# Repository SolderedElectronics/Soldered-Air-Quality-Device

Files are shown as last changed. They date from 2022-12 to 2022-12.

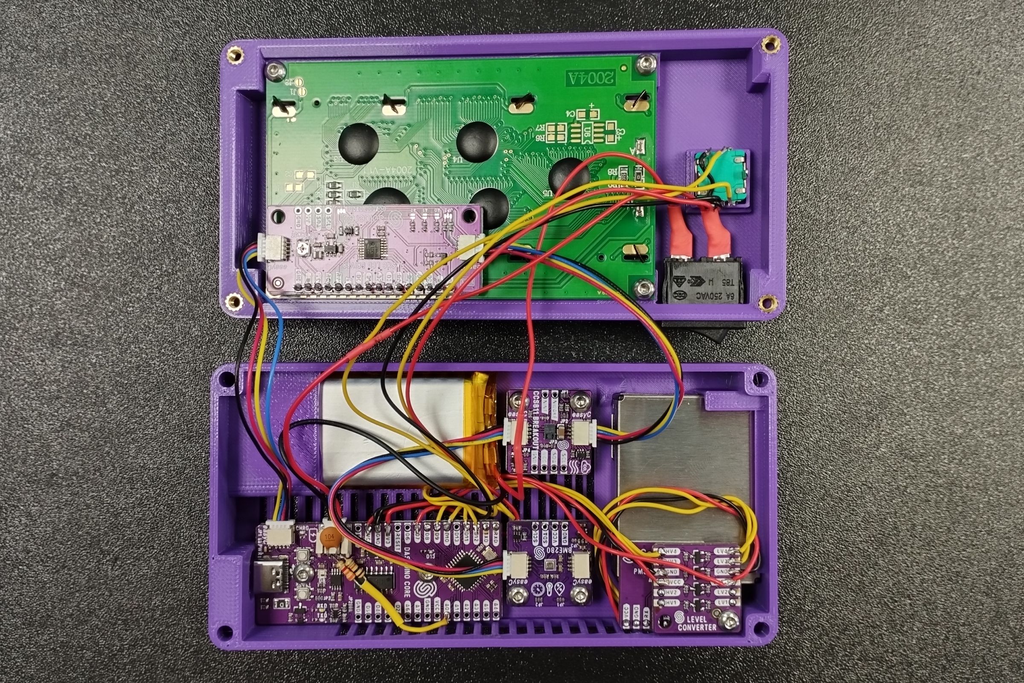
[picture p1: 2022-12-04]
Images/DeviceInside.jpg

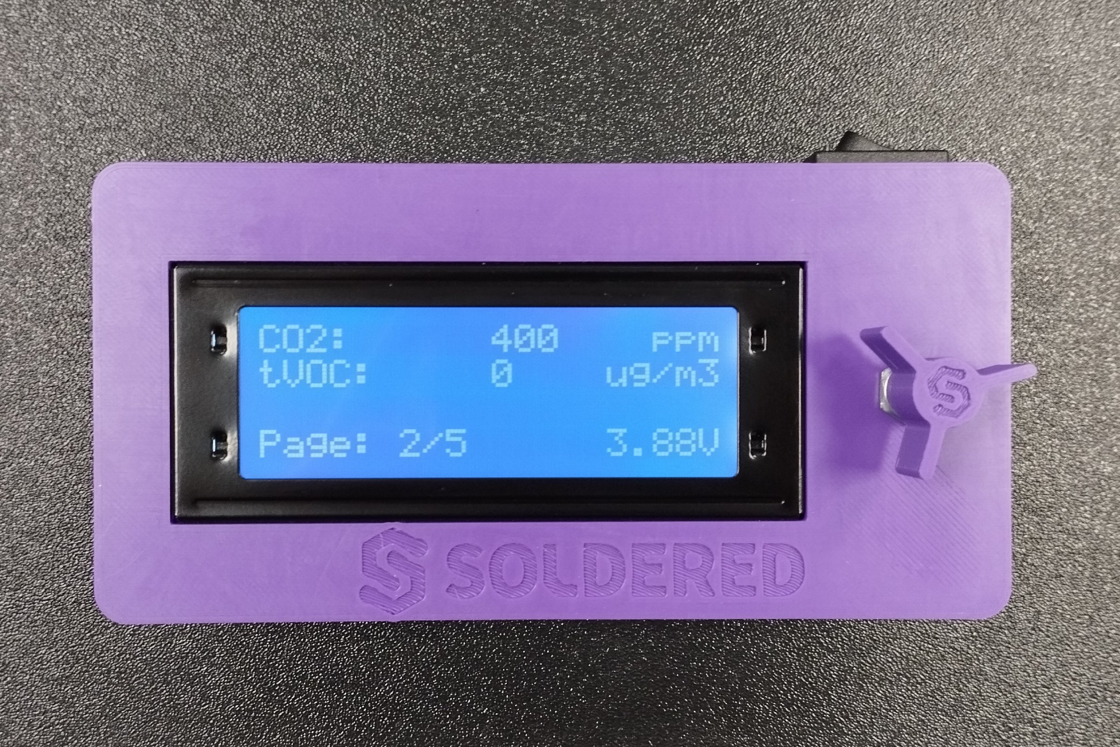
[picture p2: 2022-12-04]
Images/Page2.jpg

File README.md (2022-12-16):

# Device for measuring air quality parameters

In order to have an insight into the air quality in the places where we live, we designed a simple device that measures the parameters that determine air quality, namely: temperature, humidity, pressure, CO2, and the concentration of small-sized particles that are dispersed throughout the air. To measure these parameters, we chose sensors: BME680, CCS811, and PMS7003. In order to display the data to the user, there is an LCD screen that can display 80 characters, 20 in each of the 4 lines. The sensors are controlled by the Dasduino Core, and to make the device portable, it can also run on a battery. Navigation through a simple interface is made possible by a rotary encoder, and the 3D-printed case places all the sensors in a small space and gives it that unique maker character.

Air quality device

# Wiring diagram
Sensors and other components are connected according to the wiring diagram shown below.

schematic

## Used electronic components

* Dasduino CORE - [link](https://soldered.com/product/dasduino-core-2/)
* Enviromental & air quality sensor BME680 breakout - [link](https://soldered.com/product/senzor-kvalitete-zraka-i-okoline-bme680-2/)
* Air quality sensor CCS811 breakout - [link](https://soldered.com/product/senzor-kvalitete-zraka-ccs811-2/)
* PMS7003 senzor PM10, PM2.5 - [link](https://soldered.com/hr/proizvod/pms7003-senzor-pm10-pm2-5/) + PMS7003 sensor adapter - [link](https://soldered.com/product/adapter-za-pms7003-senzor-2/)
* Logic level converter board - [link](https://soldered.com/product/pretvarac-logickih-razina-2/)
* LCD display16x4 white/blue - [link](https://soldered.com/product/lcd-ekran-16x4-bijelo-plavi-2/) + I2C LCD driver board - [link](https://soldered.com/hr/proizvod/i2c-lcd-driver-board/)
* Rotary encoder 20mm with pushbutton - [link](https://soldered.com/product/rotary-encoder-20mm-s-pushbuttonom-2/)
* Li-ion battery 1800mAh 3.7V - [link](https://soldered.com/product/li-ion-baterija-1800mah-3-7v-2/)
* SPST panel switch elongated - [link](https://soldered.com/product/spst-panel-prekidac-duguljasti-2/)
* Resistor R1 = 10K (it's situated in [Resistor kit 400](https://soldered.com/product/set-otpornika-400-2/))
* Resistor R2 = 3.3K (it's situated in [Resistor kit 400](https://soldered.com/product/set-otpornika-400-2/))
* Ceramic capacitor 100nF 50V - [link](https://soldered.com/product/keramicki-kondenzator-100nf-50v-2/)

## Consumable material for assembling:
* PLA Soldered purple filament
* M3 Threaded inserts
* 9x Screw M3 5mm HEX - [link](https://soldered.com/product/vijak-m3-5mm-hex-2/)
* 4x Screw M3 12mm HEX - [link](https://soldered.com/product/vijak-m3-12mm-hex-2/)
* Prototyping wire AWG25 - [link](https://soldered.com/product/ica-za-prototipiranje-10m-crvena-awg25-2/)
* 3x easyC cable 10cm - [link](https://soldered.com/product/easyc-kablic-10cm-2/)
* Heatshrink - [link](https://soldered.com/product/set-termobuzira-2/)

# 3D case
In order for all the sensors and electronics to be in one place and at the same time look nice, a case was designed that was printed on a 3D printer. In order for the air to flow through the case for the sensors to measure correctly, there are openings on the back and on the top and bottom.

3d case

When we place all the sensors in the intended place in the case, it looks like this

Device inside with bme680

# How to use this device?
The device has a rotary encoder that controls the device. By turning the rotary encoder, we change the pages on which the readings are displayed. The device automatically refreshes the data every 5 seconds (it can be changed in the code by simply changing the constant), but if we want immediate reading and refreshing of the page, it is possible by pressing the button of the rotary encoder. BME680 and PMS7003 are relatively fast and with them a new reading will be obtained, while CCS811 is not so fast and if we refresh its measurements too quickly sometimes it will not be able to measure them and old measurements will be displayed. These times are of the order of several tenths, and this will not be noticed if the device refreshes itself. Depending on how many sensors are connected, we have a different number of pages, and the pages go in a circle, i.e. from the last page by turning forward, we switch to the first page and vice versa.

Page2
Page3
Page4

In the bottom right corner is the battery voltage. When the Dasduino is connected to 5V via the USB-c port, the voltage can vary because it is charging the battery. There is a switch on the device that turns the battery on and off from the circuit, i.e. when the device is connected to 5V, the battery will charge only if the switch is set to 1, otherwise, the battery will not charge.

Device From Above

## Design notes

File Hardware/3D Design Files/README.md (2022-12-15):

# 3D printing

Here are the files needed for 3D printing. We used the Prusa Mk3s+ 3D printer and the Prusa slicer for printing. 
The 3D printer settings are as follows: 
* Default speed for mk3 printers
* 15% infill
* 0.2 mm layer height 

We used PLA Soldered purple filament.

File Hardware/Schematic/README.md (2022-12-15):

schematic

The sensors and other components are connected according to the schematic. The BME680, CCS811, and the LCD support easyC so connected to the Dasduino through it for simplicity. The order of connection of easyC is not important and it does not have to be connected in the same order as in the wiring diagram. PMS7003 is connected to the PMS adapter and the same adapter to the Dasduino. It is important to note that we have to connect the serial communication through a logic level converter because the PMS uses 3.3V logic levels and the Dasduino uses 5V logic levels. The adapter independently raises the voltage to 5V, which powers the PMS sensor itself, so we don't have to take this in mind. To measure the battery voltage, it is necessary to make a voltage divider that will lower the battery voltage to the range from 0 to 1.1V so that it can be measured correctly using an internal reference, and for this, resistances R1 = 10K and R2 = 3.3K were used. If we were to measure the voltage using a 5V reference, as the battery would discharge, the reference voltage would be lower and lower and the battery reading would always be incorrect. By using an internal reference, we solved that problem because it is always fixed. To stabilize the voltage, a C1 = 100 uF capacitor was added in parallel to the battery. A switch has been added to the circuit so that it disconnects the + pole of the battery instead of going directly to the Dasduino, and it is important to note that the battery cannot be charged if the switch is off.

# Used electronic components

* Dasduino CORE - [link](https://soldered.com/product/dasduino-core-2/)
* Enviromental & air quality sensor BME680 breakout - [link](https://soldered.com/product/senzor-kvalitete-zraka-i-okoline-bme680-2/)
* Air quality sensor CCS811 breakout - [link](https://soldered.com/product/senzor-kvalitete-zraka-ccs811-2/)
* PMS7003 senzor PM10, PM2.5 - [link](https://soldered.com/hr/proizvod/pms7003-senzor-pm10-pm2-5/) + PMS7003 sensor adapter - [link](https://soldered.com/product/adapter-za-pms7003-senzor-2/)
* Logic level converter board - [link](https://soldered.com/product/pretvarac-logickih-razina-2/)
* LCD display16x4 white/blue - [link](https://soldered.com/product/lcd-ekran-16x4-bijelo-plavi-2/) + I2C LCD driver board - [link](https://soldered.com/hr/proizvod/i2c-lcd-driver-board/)
* Rotary encoder 20mm with pushbutton - [link](https://soldered.com/product/rotary-encoder-20mm-s-pushbuttonom-2/)
* Li-ion battery 1800mAh 3.7V - [link](https://soldered.com/product/li-ion-baterija-1800mah-3-7v-2/)
* SPST panel switch elongated - [link](https://soldered.com/product/spst-panel-prekidac-duguljasti-2/)
* Resistor 10K (it's situated in [Resistor kit 400](https://soldered.com/product/set-otpornika-400-2/))
* Resistor 3.3K (it's situated in [Resistor kit 400](https://soldered.com/product/set-otpornika-400-2/))
* Ceramic capacitor 100nF 50V - [link](https://soldered.com/product/keramicki-kondenzator-100nf-50v-2/)

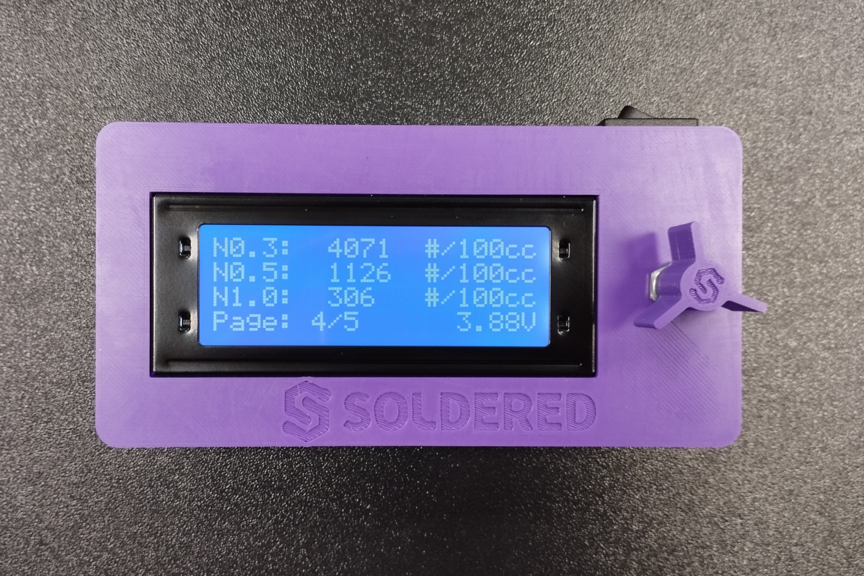
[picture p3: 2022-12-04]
Images/Page4.jpg

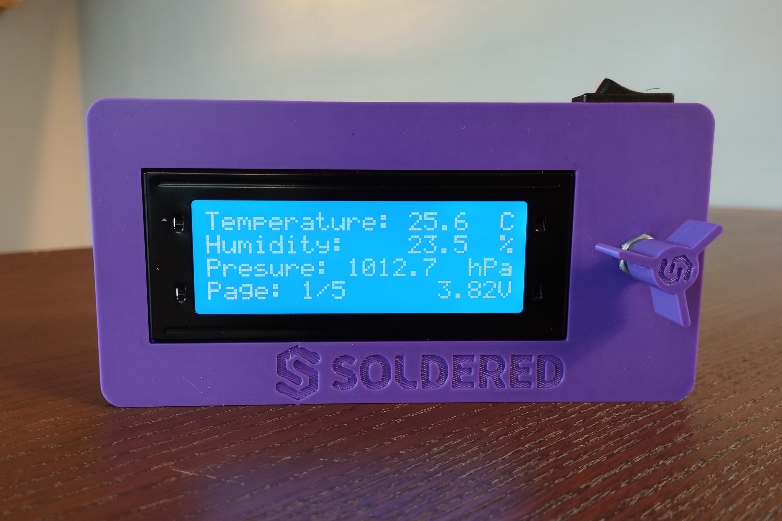
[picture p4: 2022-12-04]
Images/HeroImage.jpg

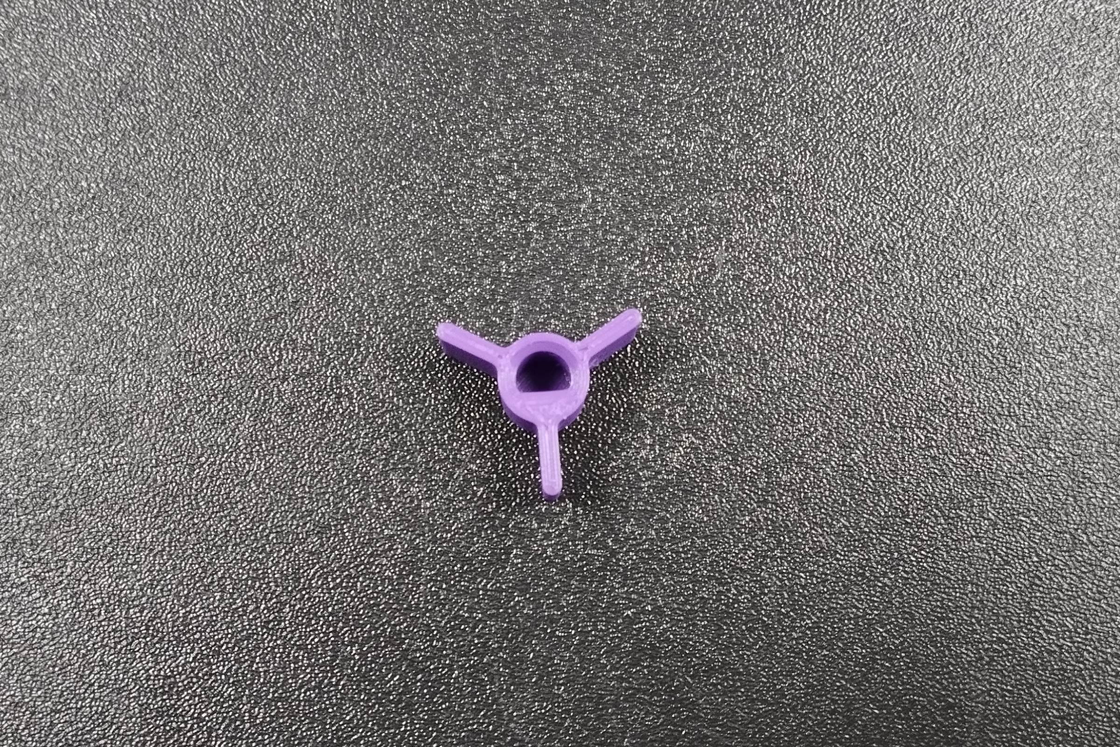
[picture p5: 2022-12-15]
Images/knob for the rotary encoder2.jpg

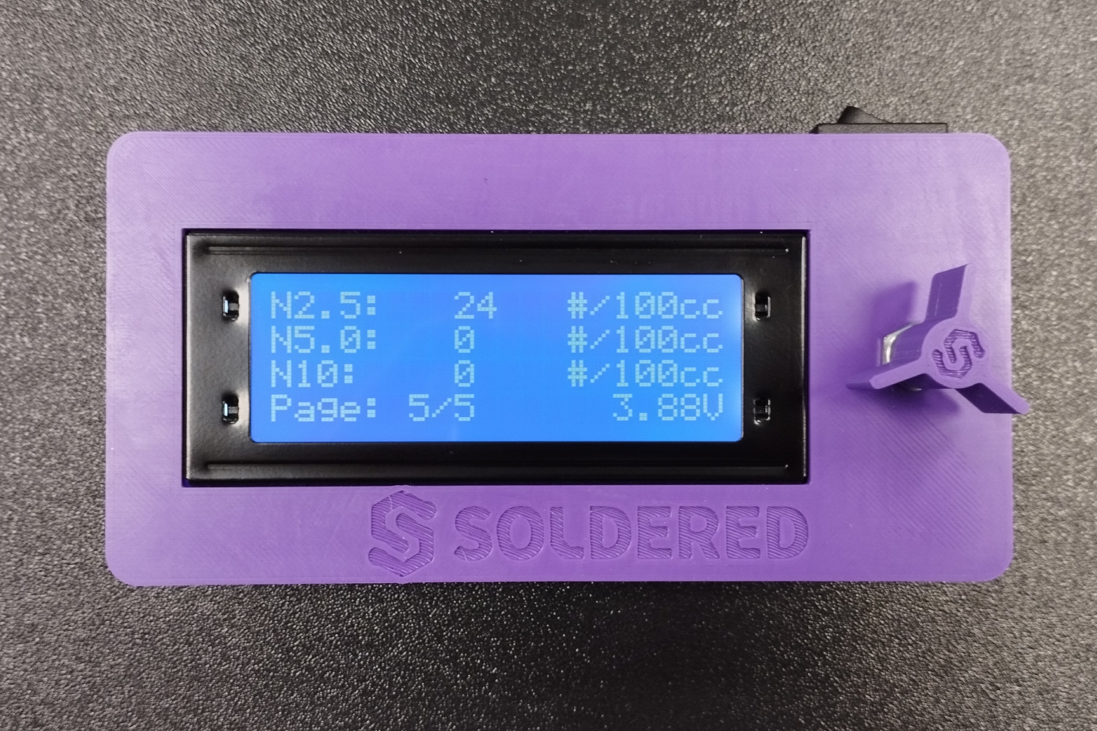
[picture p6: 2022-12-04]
Images/Page5.jpg

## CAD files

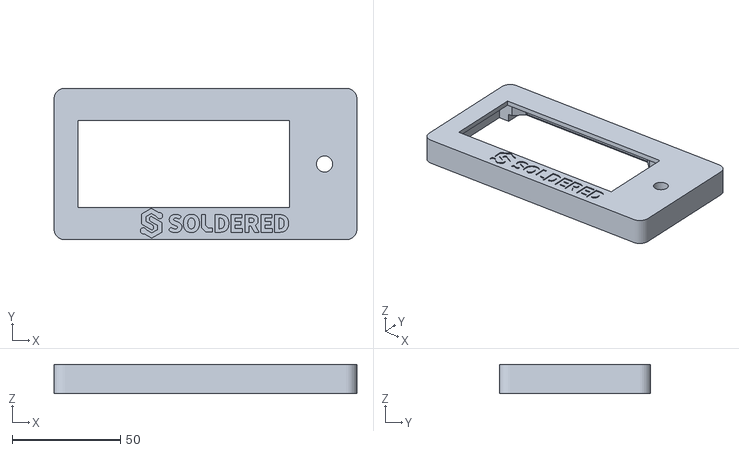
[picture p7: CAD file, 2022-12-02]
Hardware/3D Design Files/Sensors Case Top.stl
140.0 x 70.0 x 13.4

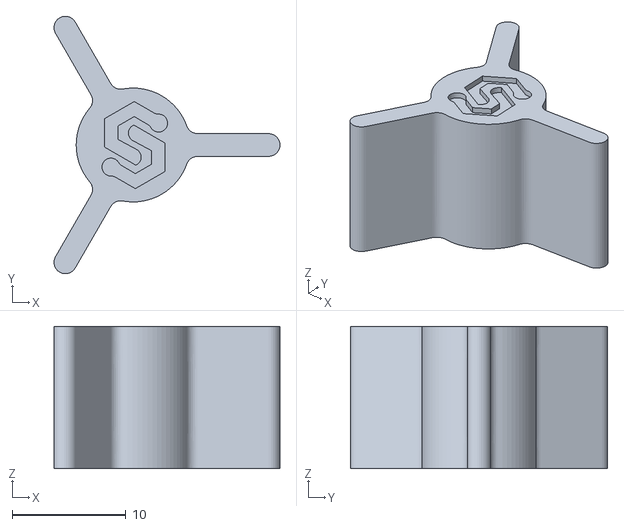
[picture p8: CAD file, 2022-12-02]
Hardware/3D Design Files/Rotary Cap.stl
19.8 x 22.6 x 12.5

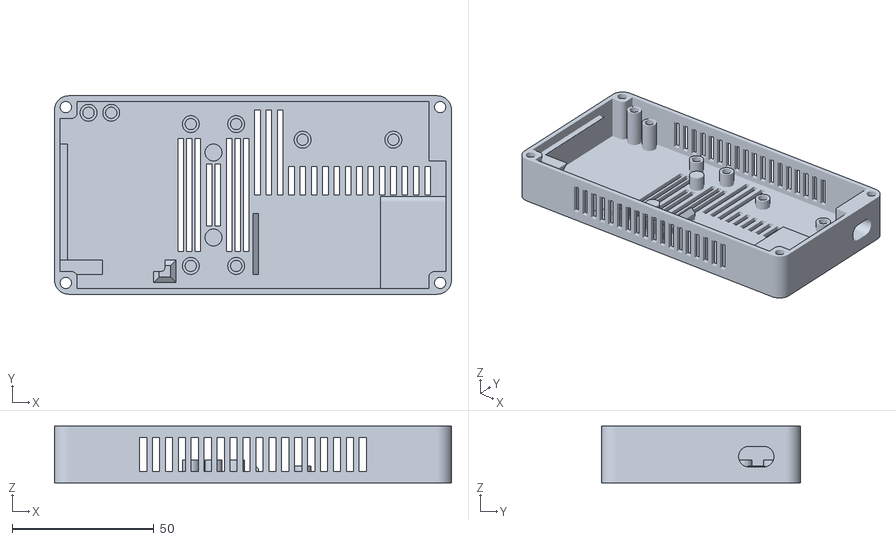
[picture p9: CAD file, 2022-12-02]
Hardware/3D Design Files/Sensors Case Bottom.stl
140.0 x 70.0 x 20.0

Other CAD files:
Hardware/3D Design Files/Rotary Cap.f3d
Hardware/3D Design Files/Sensors Case Bottom.f3d
Hardware/3D Design Files/Sensors Case Top.f3d
Hardware/3D Design Files/Sensors Case Top.f3z

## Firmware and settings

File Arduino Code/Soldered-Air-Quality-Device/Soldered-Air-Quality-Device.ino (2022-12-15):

/*
    The air quality sensor is a device that measures particulate concentration in the air and determines air quality.
    It also measures temperature, humidity and pressure.

    settings.h is a file that contains parameters for device configuration. You can configure
    which sensors want to use by simply put 0 to the certain define. BME680 is used by default and you can't disable
    them while CCS811 and PMS7003 are optional. You can also adjust refresh time, battery high and low levels values,
    temperature offset to calibrate the BME680 sensor, rotary encoder pins, and PMS7003 pins.

    gui.h is a header file that contains class GUI class definition.

    gui.cpp contains all functions from the GUI class which is used to display measurements on the screen and initialize
    sensors.

    Make sure to install next libraries:
    Soldered-LCD: https://github.com/SolderedElectronics/Soldered-LCD-library
    Soldered-BME280: https://github.com/SolderedElectronics/Soldered-BME280-BME680-Gas-Sensor-Arduino-Library
    Soldered-CCS811: https://github.com/SolderedElectronics/Soldered-CCS811-Air-Quality-Sensor-Arduino-Library
    Soldered-PMS7003: https://github.com/SolderedElectronics/Soldered-PMS7003-Particle-Sensor-Arduino-Library

    12 December 2022 by Soldered
*/

#include "src/gui.h"      // Include GUI class definition and its methods
#include "src/settings.h" // Include users settings

int page = 0, prevPage;            // Use those variables to select a page
int currentStateClock;             // Store the status of the rotary encoder clock pin (HIGH or LOW)
int lastStateClock;                // Store the PREVIOUS status of the rotary encoder clock pin (HIGH or LOW)
unsigned long lastButtonPress = 0; // Use this to store if the ROTARY_BUTTON_PIN button was pressed or not
unsigned long lastRefresh = 0;     // Use this to store last screen refresh

int maxPage = 1;  // Max number of pages, 1 for the BME that it's always in use, later is added more if needed
int pageOrder[5]; // The array which decides the order of pages we display

unsigned long time1; // Time measurement for button click

BME680 bme680;               // Define BME sensor object
CCS_811 ccs811Sensor;        // Define CCS811 sensor object
LCD lcd(20, 4);              // Define LCD object
PMS7003 pms(PMS_RX, PMS_TX); // Define PMSx003, RX, TX

GUI gui(&lcd, &bme680, &ccs811Sensor, &pms, &page, &maxPage);

void setup()
{
    // Set analog reference to 1.1V to measure battery voltage if you use this option
    if (MEASURING_BATTERY_VOLTAGE)
    {
        analogReference(INTERNAL);
    }

    // Turn the onboard LED off because we don't use it
    pinMode(LEDWS_BUILTIN, OUTPUT);
    digitalWrite(LEDWS_BUILTIN, LOW);

    // Begin I2C comunication
    Wire.begin();

    // Initialize LCD and turn the backlight on
    gui.displayBegin();

    // Set encoder and button pins as inputs with pullups
    pinMode(ROTARY_CLOCK_PIN, INPUT_PULLUP);
    pinMode(ROTARY_DATA_PIN, INPUT_PULLUP);
    pinMode(ROTARY_BUTTON_PIN, INPUT_PULLUP);

    // Read the initial state of clock pin of rotary encoder (it could be HIGH or LOW)
    lastStateClock = digitalRead(ROTARY_CLOCK_PIN);

    // Initialize BME
    gui.BMEbegin();

    if (USE_CCS_SENSOR) // Initialize CCS811
    {
        gui.CCSbegin();
        maxPage += 1; // Add 1 to max pages because the CCS needs 1 page
    }

    if (USE_PMS_SENSOR) // Initialize serial communication with PMS sensor
    {
        gui.PMSbegin();
        maxPage += 3; // Add 3 to max pages because the PMS needs 3 page
    }

    // Depending on how many pages we have, we know which sensor is used and set pages
    // Below are the indexes for each page:
    // index 1 - BME first page (1/1)
    // index 2 - CCS first page (1/1)
    // index 3 - PMS first page (1/3)
    // index 4 - PMS second page (2/3)
    // index 5 - PMS third page (3/3)
    switch (maxPage)
    {
    // Set order pages depending on which sensors using
    case 1:               // Only BME is used
        pageOrder[0] = 1; // BME first page
        break;
    case 2: // Using BME and CCS
        pageOrder[0] = 1;
        pageOrder[1] = 2;
        break;
    case 4: // Using BME and PMS
        pageOrder[0] = 1;
        pageOrder[1] = 3;
        pageOrder[2] = 4; // PMS first page
        pageOrder[3] = 5;
        break;
    case 5: // Using all 3 sensors
        pageOrder[0] = 1;
        pageOrder[1] = 2;
        pageOrder[2] = 3;
        pageOrder[3] = 4;
        pageOrder[4] = 5;
        break;
    }

    // Capture time for the values refresh
    lastRefresh = time1 = millis();

    // Delay to see splash screen
    delay(2000);

    // Read the sensors to have data to display
    gui.readSensors();

    // Set default home page
    gui.setPage(1);

    // Set the previous page to know when the page is changed
    prevPage = page;
}

void loop()
{

    // Read the current state of the rotary encoder CLK pin
    currentStateClock = digitalRead(ROTARY_CLOCK_PIN);

    // If last and current state of the rotary encoder Clock are different, then "pulse occurred"
    // React to only 1 state change to avoid double count
    if (currentStateClock != lastStateClock && currentStateClock == 1)
    {
        // If the data state is different than the Clock state then
        // the encoder is rotating "CCW" so we decrement
        if (digitalRead(ROTARY_DATA_PIN) != currentStateClock)
        {
            page--;

            // Prevent going to the negative numbers
            if (page < 0)
            {
                page = maxPage - 1;
            }
        }
        else
        {
            // Encoder is rotating CW so increment
            page++;

            // Prevent going to the more than 5 pages
            if (page > maxPage - 1)
            {
                page = 0;
            }
        }
    }

    // We save last Clock state for next loop
    lastStateClock = currentStateClock;

    // Read the button state
    int btnState = digitalRead(ROTARY_BUTTON_PIN);

    // If we detect LOW signal, button is pressed
    if (btnState == LOW)
    {
        // if 50ms have passed since last LOW pulse, it means that the
        // button has been pressed, released and pressed again
        if ((unsigned long)(millis() - lastButtonPress) > 50)
        {
            // If button is pressed, refresh screen
            if ((unsigned long)(millis() - lastRefresh) > 2000)
            {
                // Take measurements only once if the button is pressed more than one time in 2 seconds
                gui.readSensors();
                gui.setPage(pageOrder[page]);
                lastRefresh = time1 = millis();
            }
            else
            {
                // Only refresh the screen if the button is pressed more than one time in 2 sec
                gui.setPage(pageOrder[page]);
            }
        }

        // Remember last button press event
        lastButtonPress = millis();
    }

    // Put in a slight delay to help debounce the reading
    delay(1);

    // If the page is changing, change content
    if (prevPage != page)
    {
        gui.setPage(pageOrder[page]);
        prevPage = page;
    }

    // Refresh sensor readings every 5 seconds without blocking the code
    if ((unsigned long)(millis() - time1) > REFRESH_DATA_TIME)
    {
        // Set sensor readings depending on the page we are
        gui.readSensors();
        gui.setPage(pageOrder[page]);

        // Reset timer after refreshing
        time1 = millis();
    }
}

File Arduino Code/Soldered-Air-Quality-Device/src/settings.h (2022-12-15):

/**
 ***************************************************
 *
 * @file        settings.h
 *
 * @brief       Settings for the device
 *
 * @copyright   GNU General Public License v3.0
 *
 * @author      Karlo Leksic for Soldered.com
 *
 ****************************************************/

// Sensors settings - Put 0 if you won't to use these sensors
#define USE_PMS_SENSOR 1 // This variable decides the usage of the PMS7003 sensor
#define USE_CCS_SENSOR 1 // This variable decides the usage of the CCS811 sensor

#define TEMP_OFFEST 0 // Set the temperature offset if you want to calibrate the sensor

#define BATTERY_R1 10000 // The resistor 1 on the voltage divider for measure battery voltage in Ohms
#define BATTERY_R2 3300  // The resistor 2 on the viltage divider for measure battery voltage in Ohms

// Battery measuring enable - if you won't measure the battery, put 0
#define MEASURING_BATTERY_VOLTAGE 1

// The pin on the Dasduino which is connected voltage divider for measuring battery voltage
#define BATTERY_MEASURE_PIN A0

#define REFRESH_DATA_TIME 10000 // Refresh sensors readings every 10000 ms (10 sec). This is also the minimum time.

// Rotary Encoder Inputs
#define ROTARY_CLOCK_PIN  7  // Clock pin connected to D7
#define ROTARY_DATA_PIN   9  // Data pin connected to D9
#define ROTARY_BUTTON_PIN 10 // rotaryEncoderBtn button pin connected to D10

// PMS7003
#define PMS_RX 11 // RX pin of the MPS7003 for serial comunication
#define PMS_TX 12 // TX pin of the MPS7003 for serial comunication

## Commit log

2022-12-01 Added functional code for a device
2022-12-01 Changed file name to open properly with Arduino IDE
2022-12-02 Changed sketch name, folder structure, added 3D files.
    [Rotary Cap.f3d, Rotary Cap.stl, Sensors Case Bottom.f3d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]
2022-12-02 Added readme files for Images and Schematic folders.
2022-12-09 Changed lib for bme680 to soldered and add 2 second limit for refresh screen
2022-12-12 Added functions to read each sensor, store sensor values in class, and refresh data every 10 seconds
2022-12-13 Added comments and corrected documentation
    [Soldered-Air-Quality-Device.ino, gui.cpp, settings.h]
2022-12-13 Uncomment built-in led
2022-12-15 Added schematic and edited that readme
2022-12-15 Added schematic in readme
2022-12-15 added consumable material in readme
2022-12-15 remove consumable material from 3d design file
2022-12-16 Added resistor numbers in readme
